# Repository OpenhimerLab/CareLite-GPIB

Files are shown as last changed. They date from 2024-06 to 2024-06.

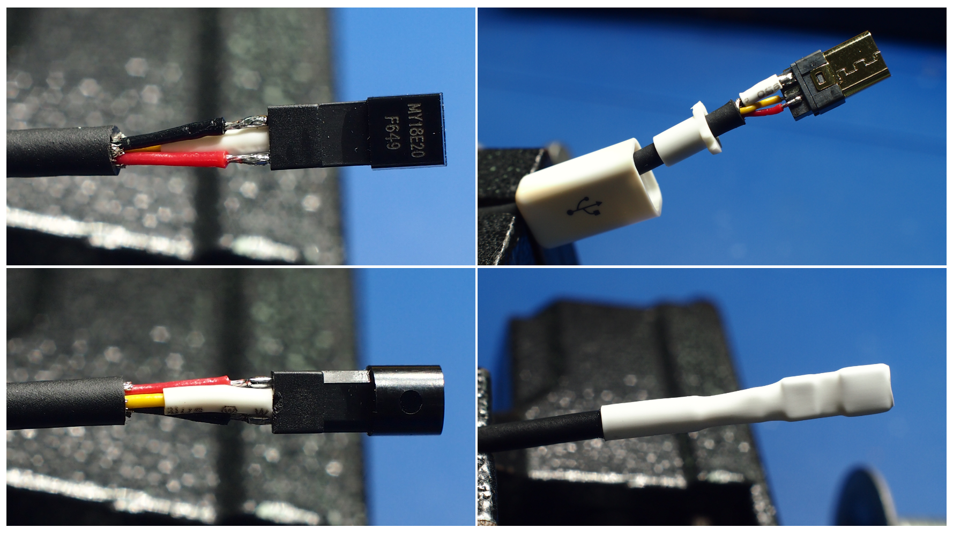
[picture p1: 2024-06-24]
HW/18B20 Soldering.png

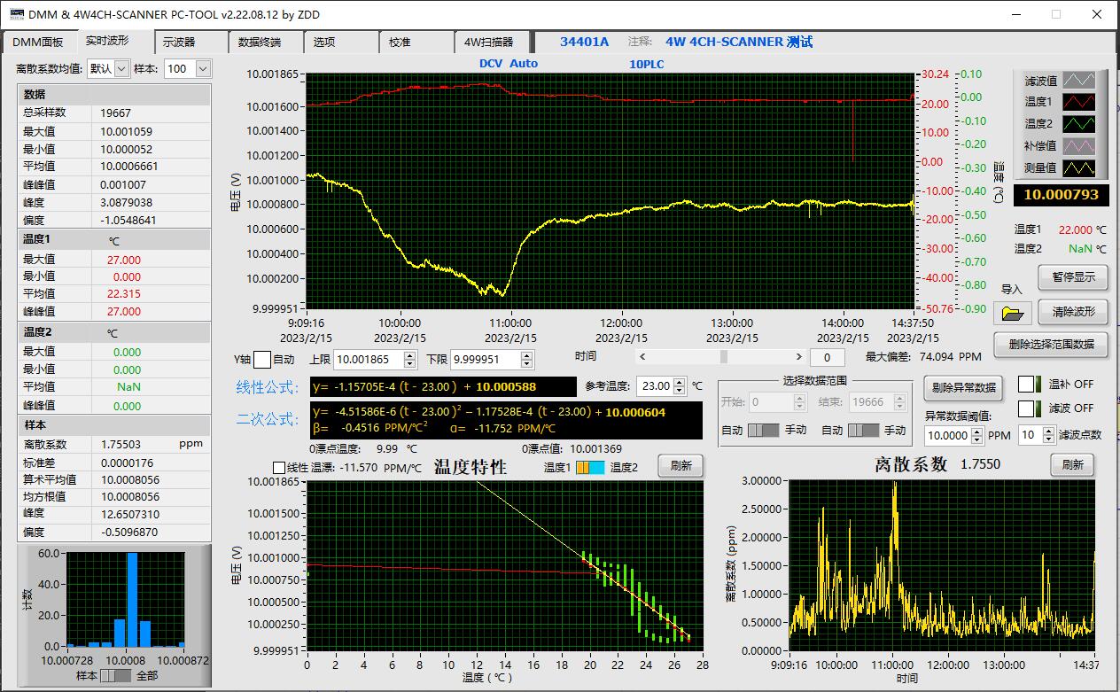
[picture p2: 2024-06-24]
PC Software 2.jpg

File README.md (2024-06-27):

# CareLite-GPIB
CareLite is an open-source, tiny, small USB-GPIB adaptor based on STM32 with temperature sensors. 
It uses VCP (Virtual COM Port) and USB Type-C connector, without the need for external power; 
also with dedicated PC software (but not limited to), 
easy GPIB connection can be established and Prologix-like command protocol makes the compatiblity better, and real-time temp logging can be done by DS18B20 or so.




****I am NOT the author with no any relationship or benefit conflict with the author. I have no commercial intention to introdue this project and I have no intention to make benefits from this. 
All responsibility and risk or financial loss should be taken by the DIYers yourselves. The project is introduced and shared "AS IS".
Many functions, issues may exisit so use it at your own risk.


There are 2 version of MeterCare USB-GPIB converter, while sharing the same PC host Software, the firmware is unclear that both version could be applied.
We choose to introduce and share the "Lite" version firstly, as it is a simple, costless design somehow like AR488, 
but the designer reserves potentials to expand other functionality like temperature, humidity sensing ability (there is an UART+DS18B20 port, with proper firmware, it can be amazing for its various functionality!).
Schematic_CareLite_V1 21

By the STM32F401, the CareLite can perform GPIB-USB conversion. 
In addition, there is a connector called MeterLink that provides the integration of multiple sensors(1 DS18B20 is confirmed to be functional).

PCB4

PCB3
PCB2

Till now, at least 1 DS18B20 OneWire Temperature sensor can be used for logging temperature (by using MeterLink).



PC Software 2

With the software written by "ZDD", you can connect a DMM and do a logging of both volt/ohm and temperature, and it will simutaneously calculate the math like temp.Co, or the deviation of logged data.
This makes it very clear to understand the dependency of multiple variables and its statistical property.


Also note that the software by ZDD is Labeview-based, you need to install:
1. NI Labview runtime
2. Local emulator to deal with encoding problems, as it is originally based on GBK simplified chinese, not UTF-8.
MultiTemp

A sensor board with BMP180 and DS18B20, SHT2X is also possible for environment data logging, there is UART1 definition in MeterLink;
so it might be possible functional. This expansion board is mainly for the "Care" USB-GPIB, not sure if it is functional on CareLite.
PC Software 1
SW in USE 2
SW in USE 1

The firmware is a bit messy, so try and find the best one for yourself. And explore the function, the Care ecosystem is very potential.
The protocol and communication is very like Prologix, using "++" command system, there are some explaination files, but it's in simplified Chinese,
for now I have no time to translate it, so please try by your own self. 
All in all, this is a tiny, easy to use GPIB adaptor for many devices, somthing like a STM32-based AR488 but with dedicated PC sotware!

For COPYright:


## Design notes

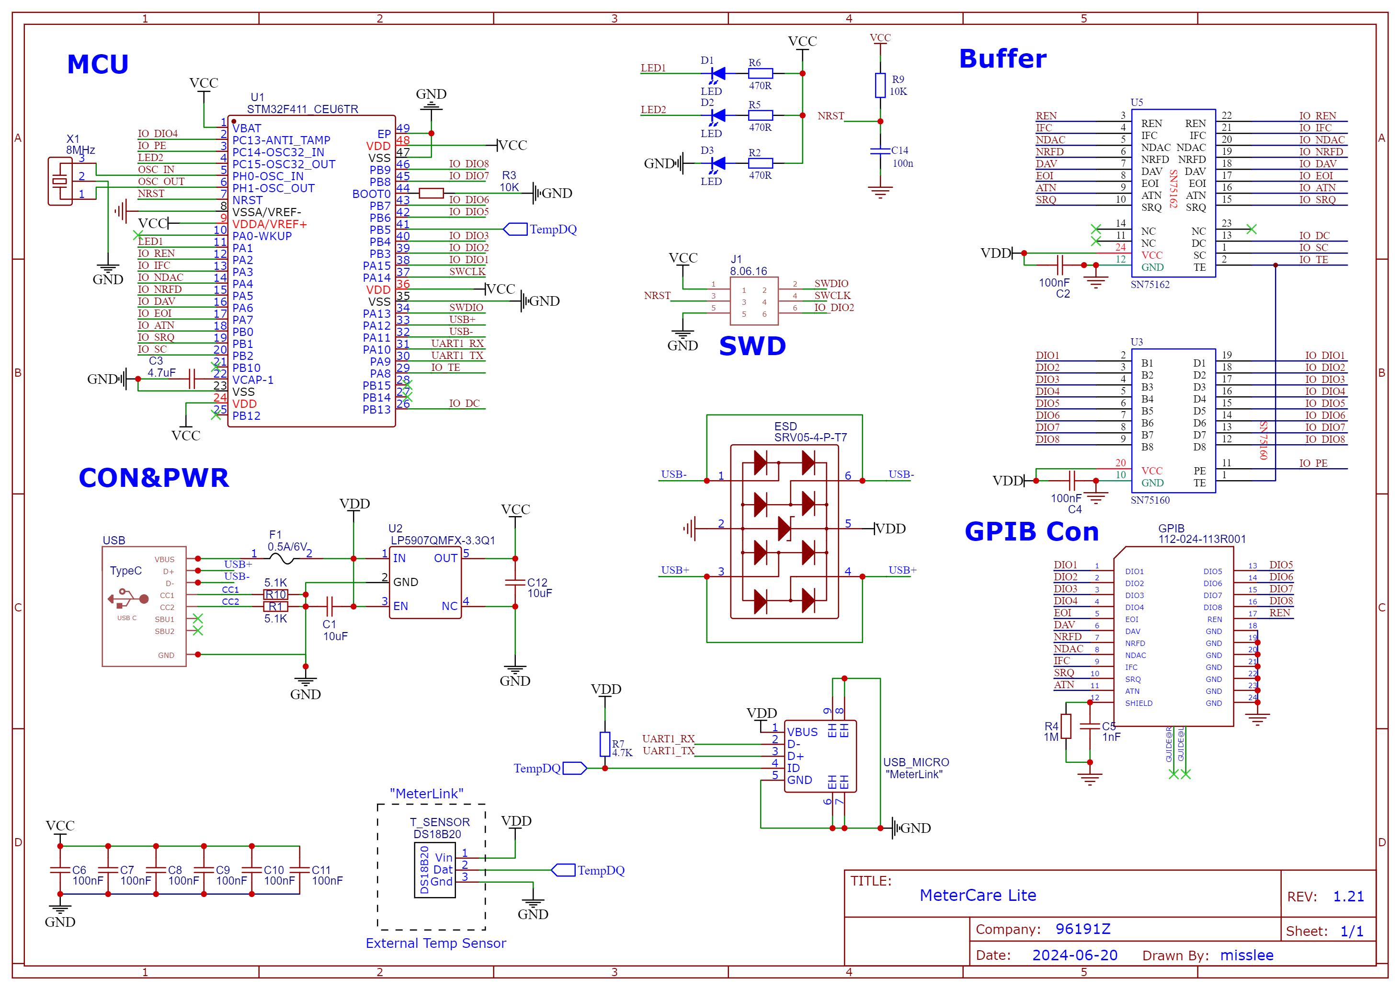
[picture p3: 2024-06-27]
Schematic_CareLite_V1.21.png

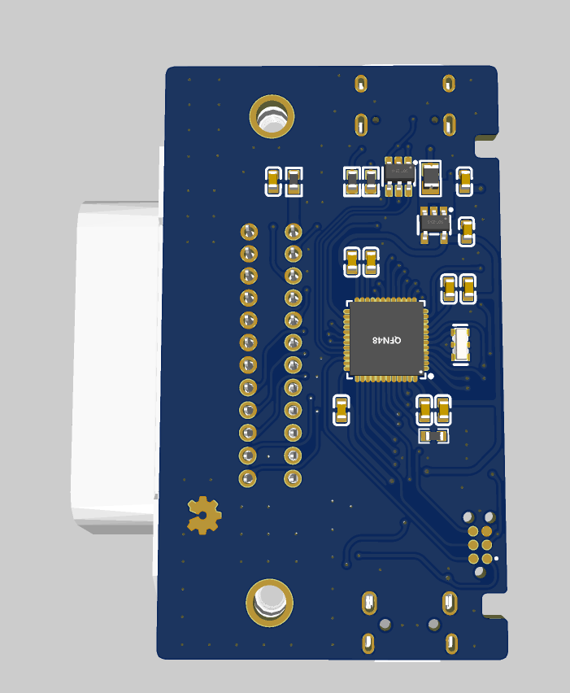
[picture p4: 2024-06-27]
PCB2.png

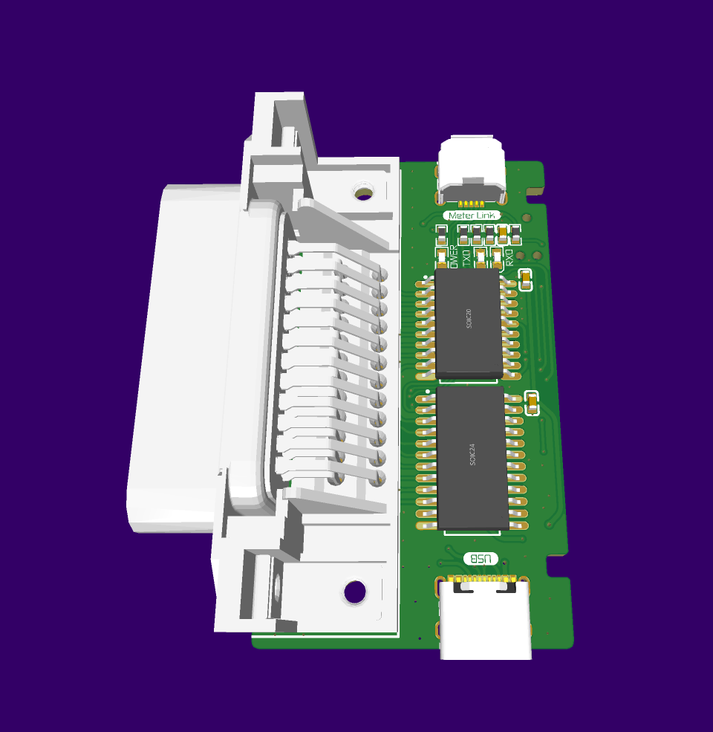
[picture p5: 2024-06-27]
PCB3.png

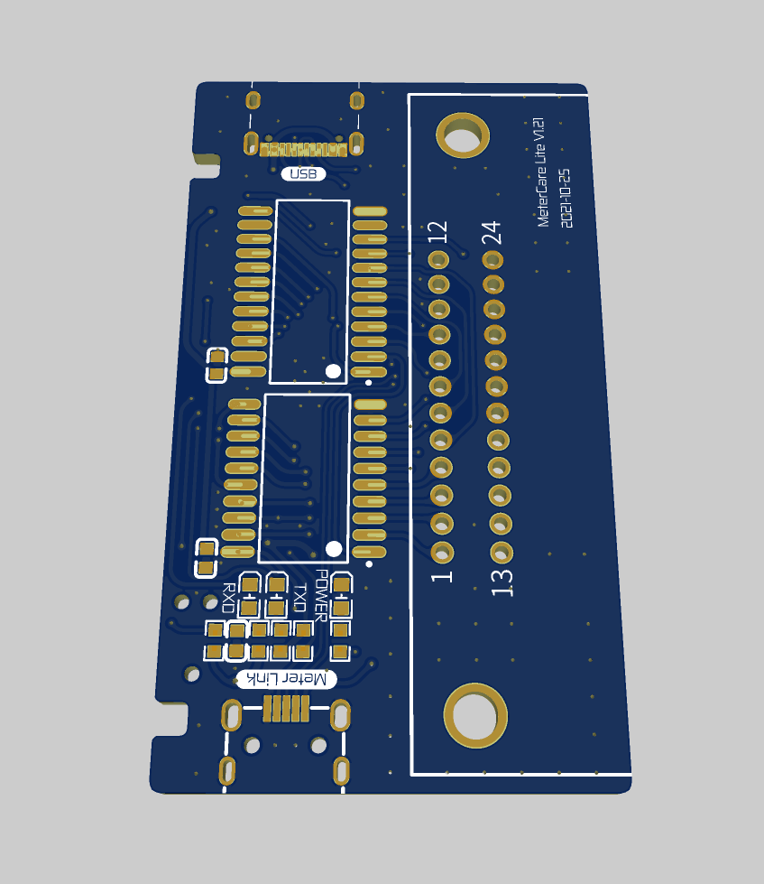
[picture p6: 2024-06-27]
PCB.png

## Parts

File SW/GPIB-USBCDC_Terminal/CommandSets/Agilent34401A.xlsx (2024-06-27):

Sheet: 仪器命令
命令内容 | 空格 | 分割符 | 空格 | 命令是否有返回信息(是:1,否0) | 空格 | 分割符 | 空格 | 命令说明信息
*IDN? |  | # |  | 1 |  | # |  | 询问仪器名称、版本等信息
*RST |  | # |  | 0 |  | # |  | 重置设置为默认值
*TST? |  | # |  | 0 |  | # |  | 仪器自检
SYSTem:ERRor? |  | # |  | 1 |  | # |  | 询问当前错误信息
*CLS |  | # |  | 0 |  | # |  | 清除错误
*CLS;:READ? |  | # |  | 1 |  | # |  | 读取当前值
*CLS;:MEASure:VOLTage:DC? 1E-1,1E-7 |  | # |  | 1 |  | # |  | 指定在100mv(0.1,1E-1 V),分辨率为(0.0000001,1E-7 ) (6位半)测量直流电压\n 该方式不具有灵活性,建议使用CONF:VOLT:DC 1E-1, 1E-7 ; :TRIG:SOUR BUS| IMMediate | EXTernal ; : READ? \n 或 CONF:VOLT:DC 1E-1, 1E-7 ; :TRIG:SOUR BUS | IMMediate | EXTernal ; : INIT ; :FETC? \n 这两种方式
*CLS;:CONFigure:VOLTage:DC 1E-1, 1E-7 ; :TRIG:SOURce IMMediate ;:READ? |  | # |  | 1 |  | # |  | 指定在100mV量程,6位半测量直流电压,\n触发方式为立即执行
*CLS;:CONFigure:VOLTage:DC 1E-2, 1E-7 ; :TRIG:SOURce IMMediate ; :INIT ; :FETC? |  | # |  | 1 |  | # |  | 指定在10mV量程,6位半测量交流电压(AC模式设置分辨率仅仅改变前面板显示,数据始终以6位半模式储存),\n触发方式为立即执行
*CLS;:CONFigure:CURRent:AC 1E-3, 1E-6 ; :TRIG:SOURce IMMediate ; :INIT ; :FETC? |  | # |  | 1 |  | # |  | 指定在1mA量程,5位半测量交流电流(AC电流最多支持5未半),\n触发方式为立即执行
*CLS;:CONFigure:RESistance ; :TRIG:SOURce IMMediate ; :INIT ; :FETC? |  | # |  | 1 |  | # |  | 双线测量电阻,测量电阻不要指定量程和分辨率
*CLS;:CONFigure:FRESistance ; :TRIG:SOURce IMMediate ; :INIT ; :FETC? |  | # |  | 1 |  | # |  | 四线测量电阻,测量电阻不要指定量程和分辨率
*CLS;:SENSe:DETector:BANDwidth? |  | # |  | 1 |  | # |  | 询问当前 AC 滤波器频率
*CLS;:SENSe:DETector:BANDwidth 20 |  | # |  | 0 |  | # |  | 设置当前 AC 滤波器频率 只有 3 ,20 ,200 可选，值越低，速度越慢
*CLS;:CONFigure:CONTinuity ; :TRIG:SOURce IMMediate ; :INIT ; :FETC? |  | # |  | 1 |  | # |  | 开路测试
*CLS;:CONFigure:DIODe ; :TRIG:SOURce IMMediate ; :INIT ; :FETC? |  | # |  | 1 |  | # |  | 二极管测试
*CLS;:SENSe:FUNCtion "VOLTage:DC" |  | # |  | 0 |  | # |  | 使用直流电压测量功能
*CLS;:SENSe:FUNCtion "CURRent:AC" |  | # |  | 0 |  | # |  | 使用交流电流测量功能
*CLS;:SENSe:FUNCtion? |  | # |  | 1 |  | # |  | 当前使用的功能
*CLS;:SENSe:FUNCtion "PERiod" |  | # |  | 0 |  | # |  | 周期测量功能
*CLS;:SENSe:FUNCtion "FREQuency" |  | # |  | 0 |  | # |  | 频率测量功能
*CLS;:SENSe:FUNCtion "VOLTage:DC:RATio" |  | # |  | 0 |  | # |  | DC信号电压与参考电压比率
*CLS;:DISPlay OFF |  | # |  | 0 |  | # |  | 关闭仪器面板显示
*CLS;:DISPlay ON |  | # |  | 0 |  | # |  | 开启仪器面板显示
*CLS;:DISPlay? |  | # |  | 1 |  | # |  | 询问当前仪器屏幕是否开启
*CLS;:DISPlay:TEXT "HelloAgilent" |  | # |  | 0 |  | # |  | 将字符串 "HelloAgilent" 显示到仪器屏幕显示
*CLS;:DISPlay:TEXT:CLEar |  | # |  | 0 |  | # |  | 清除屏幕显示的文字
*CLS;:DISPlay:TEXT? |  | # |  | 1 |  | # |  | 询问当前仪器屏幕上显示的内容
*CLS;:SYSTem:BEEPer |  | # |  | 0 |  | # |  | 让仪器发出一声蜂鸣
*CLS;:SYSTem:BEEPer:STATe ON |  | # |  | 0 |  | # |  | 开启仪器蜂鸣
*CLS;:SYSTem:BEEPer:STATe? |  | # |  | 1 |  | # |  | 询问当前蜂鸣器状态
 |  | # |  |  |  | #
 |  | # |  |  |  | #
 |  | # |  |  |  | #
 |  | # |  |  |  | #
 |  | # |  |  |  | #
 |  |  |  |  |  | #

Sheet: 正则表达式
#RegexExpression标识（!2） | 空格 | 表达式内容 | 空格 | 分割符 | 空格 | 表达式说明信息
!2 |  | ([A-Za-z]{7}-)|([0-9]{5})|([0-9]) |  | # |  | 取出7个字母加一个减号(-)的部分 \n接着往后 取出一个5位数 最后取出 一位数
!2
!2
!2
!2
!2
!2
!2
!2
!2
!2
!2
!2
!2
!2
!2
!2
!2
!2
!2

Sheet: GNUCoreutils命令
#GNUCoreutils命令 标识 ！3 | 空格 | 表达式内容 | 空格 | 分割符 | 空格 | 表达式说明信息
!3 |  | awk -F, "{print $1 \" \" $2}" |  | # |  | 取出以逗号","为分割符的第一列 第二列，第一列和第二列之间用空格分隔
!3 |  | tr "[A-Z]" "[a-z}" |  | # |  | 转换所有大写字母为小写
!3 |  | tr [:lower:] [:upper:] |  | # |  | 转换所有小写字母为大写
!3 |  | tr [:upper:] [:lower:] | sed -e "s/\b\(.\)/\u\1/g" |  | # |  | 只大写单词的第一个字母,其它所有字母小写
!3 |  | tr [:upper:] [:lower:] | sed -e "s/\b\(.\)/\u\1/g" | sed "s@[^a-zA-Z][a-z][^a-zA-Z]@\U&@g" |  | # |  | 只大写单词的第一个字母,但是单个字母的全部大写
!3 |  |  |  | #
!3 |  |  |  | #
!3 |  |  |  | #
!3 |  |  |  | #
!3 |  |  |  | #
!3 |  |  |  | #
!3 |  |  |  | #
!3 |  |  |  | #
!3 |  |  |  | #
!3 |  |  |  | #
!3 |  |  |  | #
!3 |  |  |  | #
!3 |  |  |  | #
!3 |  |  |  | #
!3 |  |  |  | #
!3 |  |  |  | #
!3 |  |  |  | #
!3 |  |  |  | #
 |  |  |  | #

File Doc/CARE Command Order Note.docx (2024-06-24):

字符串命令

一．基本设置

USB连接之后串口设置，115200，N，8，1

字符串命令时候串口以及TCP调试都需要“\r\n”(0x0D 0x0A)作为结束，返回命令也都是“\r\n”(0x0D 0x0A)作为结束

开机默认透传GPIB地址为23，自动收发模式，不改变任何设置直接和23地址字符串透传，自动收发模式。如下图，23地址为3458，直接发送3458的采集命令“DCV 10”，自动返回测量数据

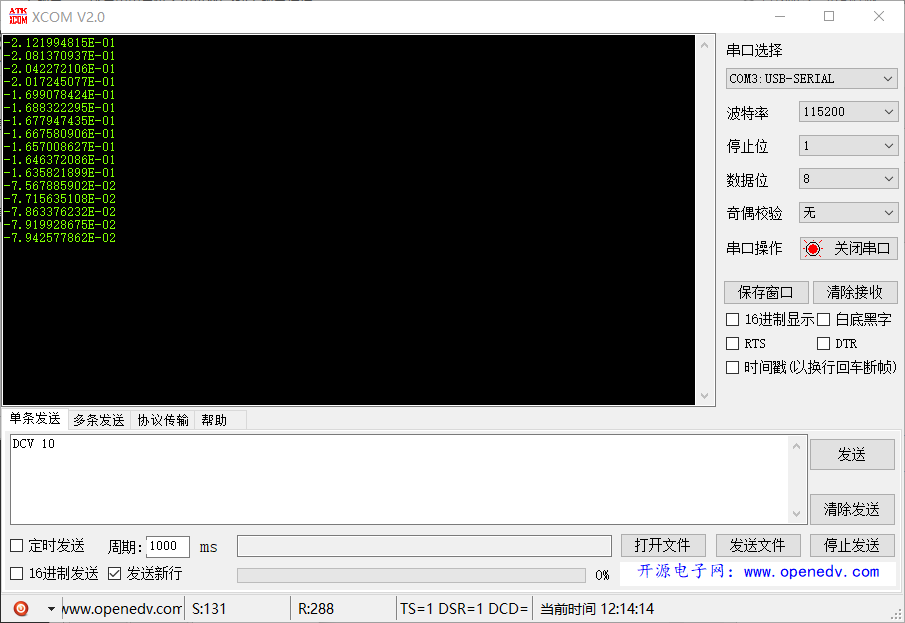
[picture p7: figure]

二．测试命令：CARE?

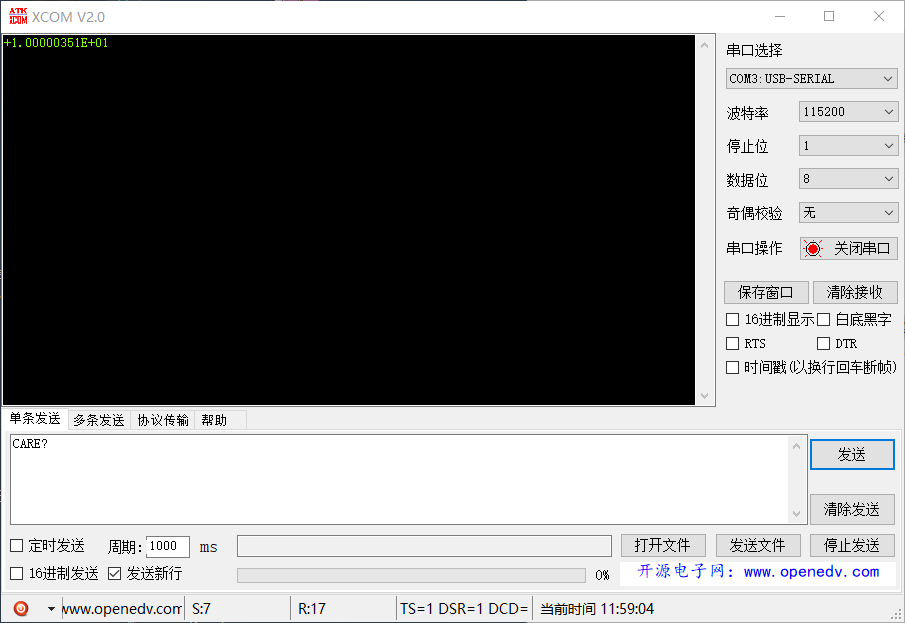
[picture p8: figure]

三．LAN连接IP获得：CARE_IP? （LAN IP地址，获取WIFI地址命令暂时还在测试）

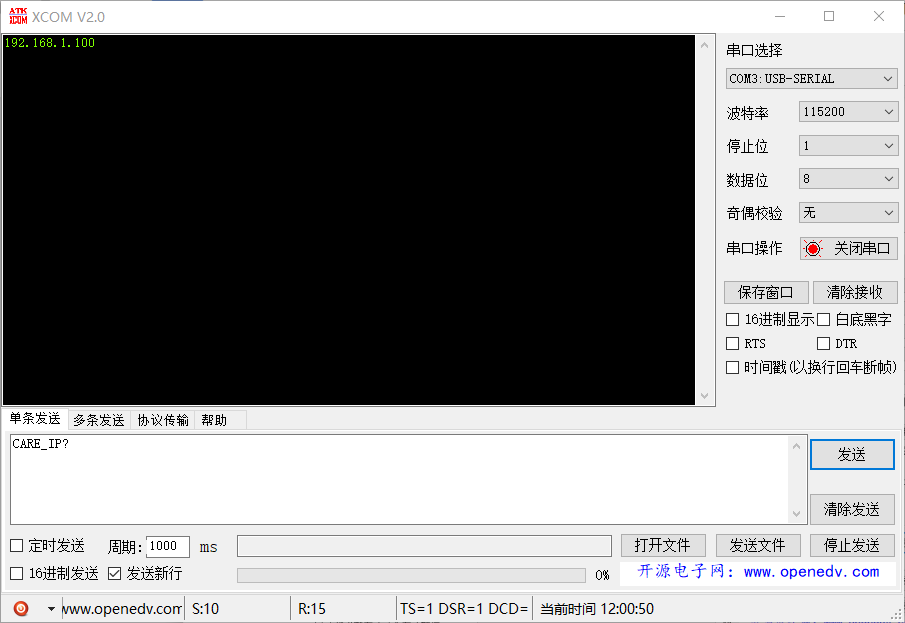
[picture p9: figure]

四．WIFI_GPIB重启：CARE_RESET

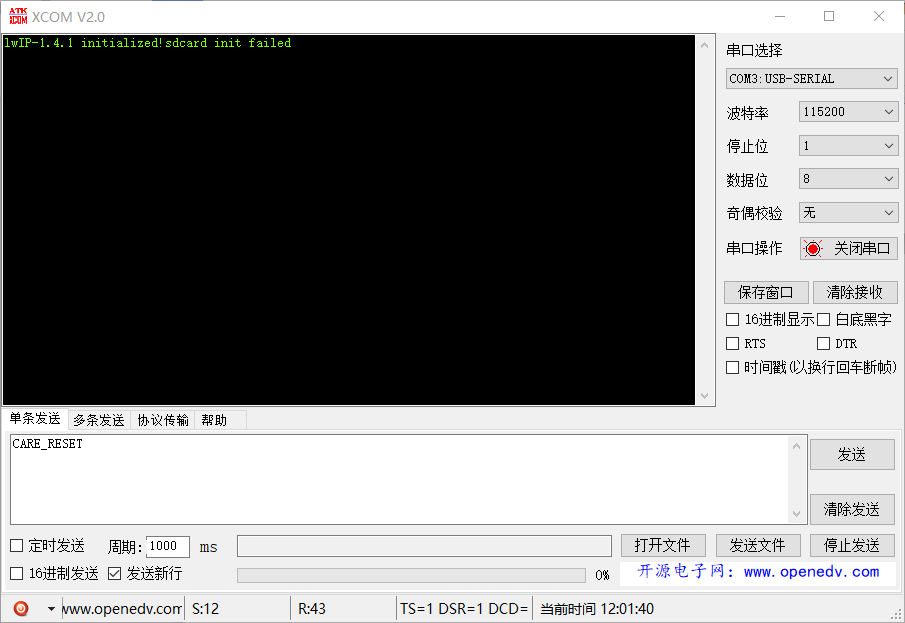
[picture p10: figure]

五．电池电压：CARE_VOLT? （0413位4.13V）

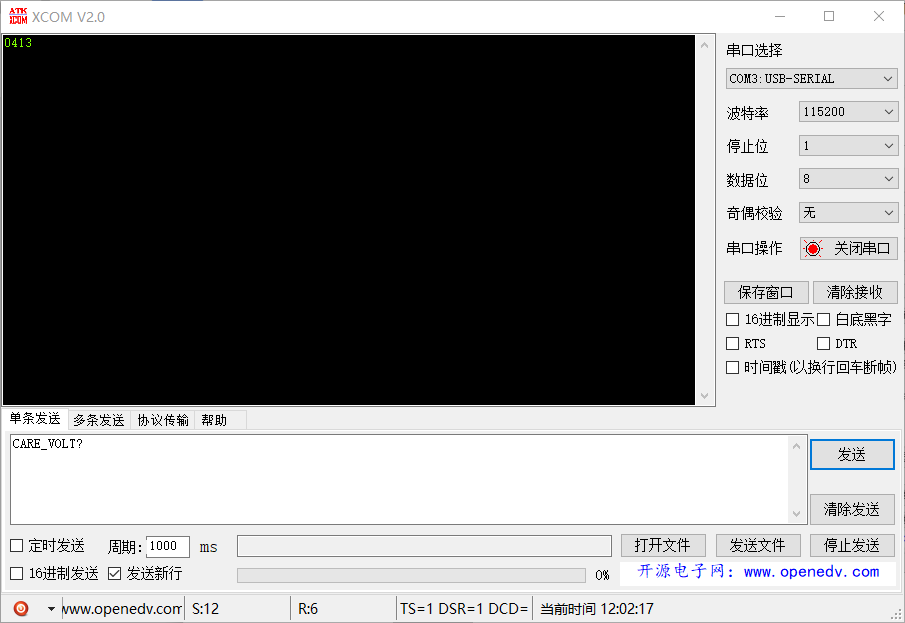
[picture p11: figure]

6． 改变透传地址：CARE_ADDR:22 （22为设置的新地址）

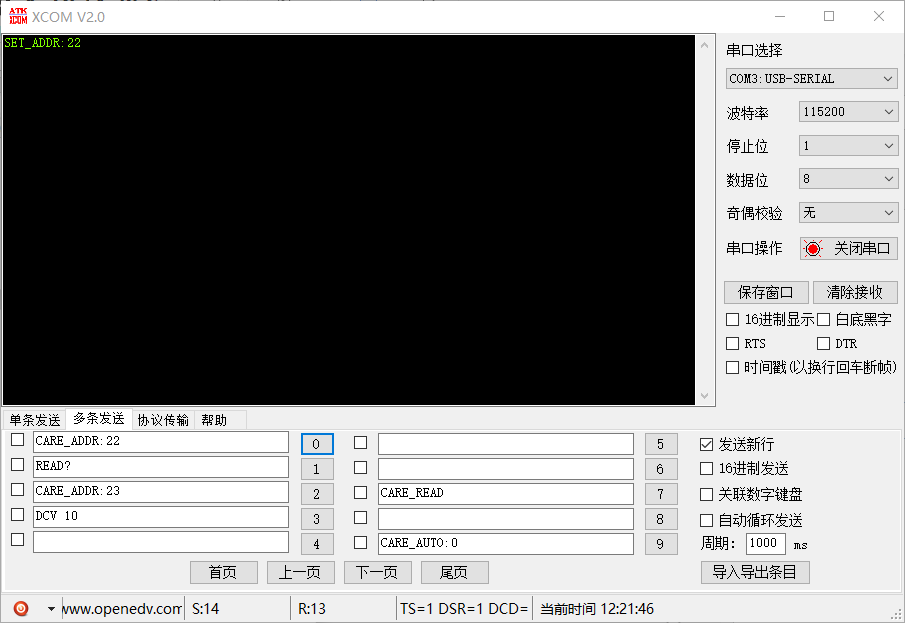
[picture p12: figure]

7． 改变自动收发模式：CARE_AUTO:1 （1|0为打开或关闭自动收发模式）

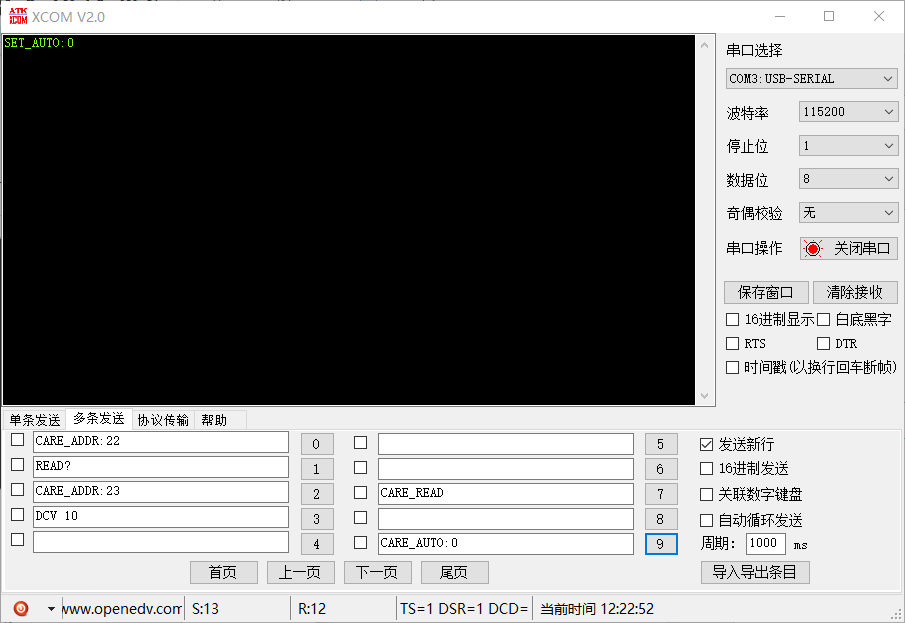
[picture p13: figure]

8． 关闭自动收发模式时候读取数据：CARE_READ

依次发送命令(22地址为AG34401)

1. CARE_AUTO:0 （关闭自动收发模式）
2. CARE_ADDR:22 （改变当前仪表地址）
3. READ? （发送AG34401采集命令READ?）
4. CARE_READ （发送命令由WIFI-GPIB回读34401数据）

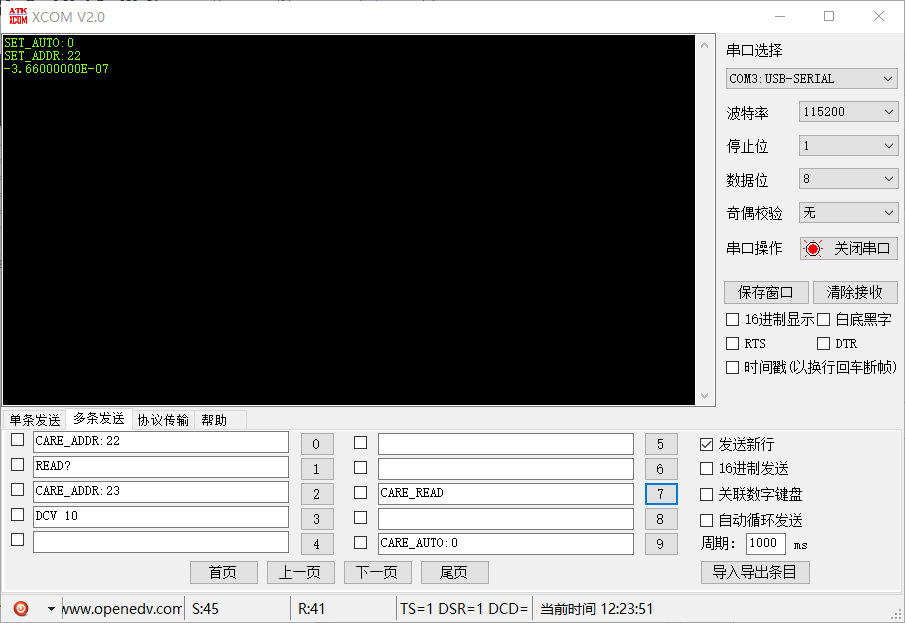
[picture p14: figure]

九．多个仪表连接实例：（22为AG34401，23为3458）

1. CARE_AUTO:0 （关闭自动收发模式）
2. CARE_ADDR:22 （改变当前仪表地址为22）
3. READ? （发送AG34401采集命令READ?）
4. CARE_ADDR:23 （改变当前仪表地址为23）
5. DCV 10 （发送HP3458采集命令DCV 10）
6. CARE_ADDR:22 （改变当前仪表地址为22）
7. CARE_READ （发送命令由WIFI-GPIB回读34401数据）
8. 得到34401采集数据
9. CARE_ADDR:23 （改变当前仪表地址为23）
10. CARE_READ （发送命令由WIFI-GPIB回读34401数据）
11. 得到3458采集数据

十．释放仪表到LOCAL状态：CARE_LOC

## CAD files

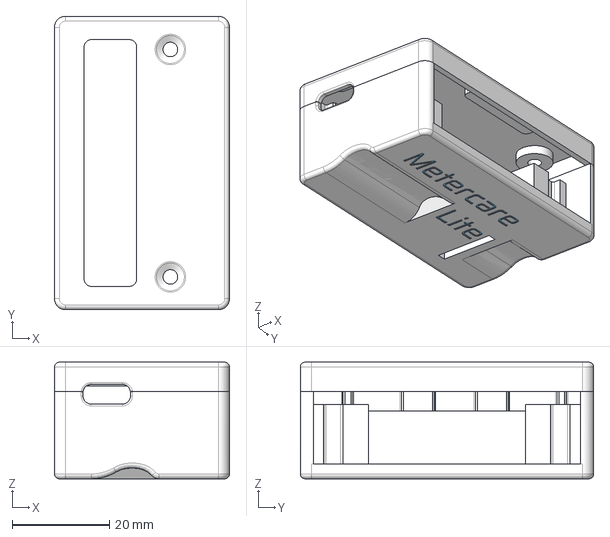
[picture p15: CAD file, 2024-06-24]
Case 3D/metercare lite Ver0.23.step
36.0 x 60.4 x 24.0 mm

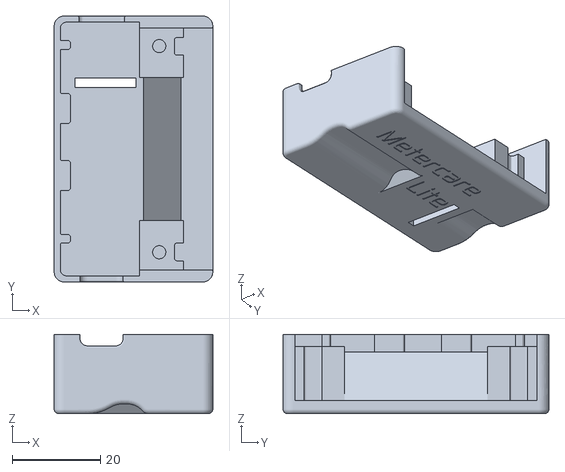
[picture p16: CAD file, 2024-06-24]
Case 3D/Top.STL
36.0 x 60.4 x 18.0

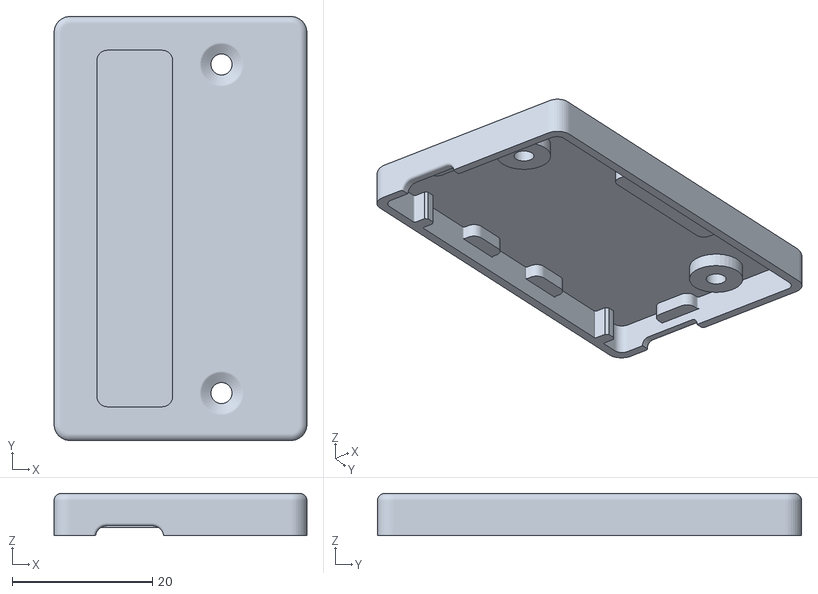
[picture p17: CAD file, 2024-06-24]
Case 3D/Bottom.STL
36.0 x 60.4 x 6.00

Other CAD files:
Case 3D/metercare lite Ver0.23.STL

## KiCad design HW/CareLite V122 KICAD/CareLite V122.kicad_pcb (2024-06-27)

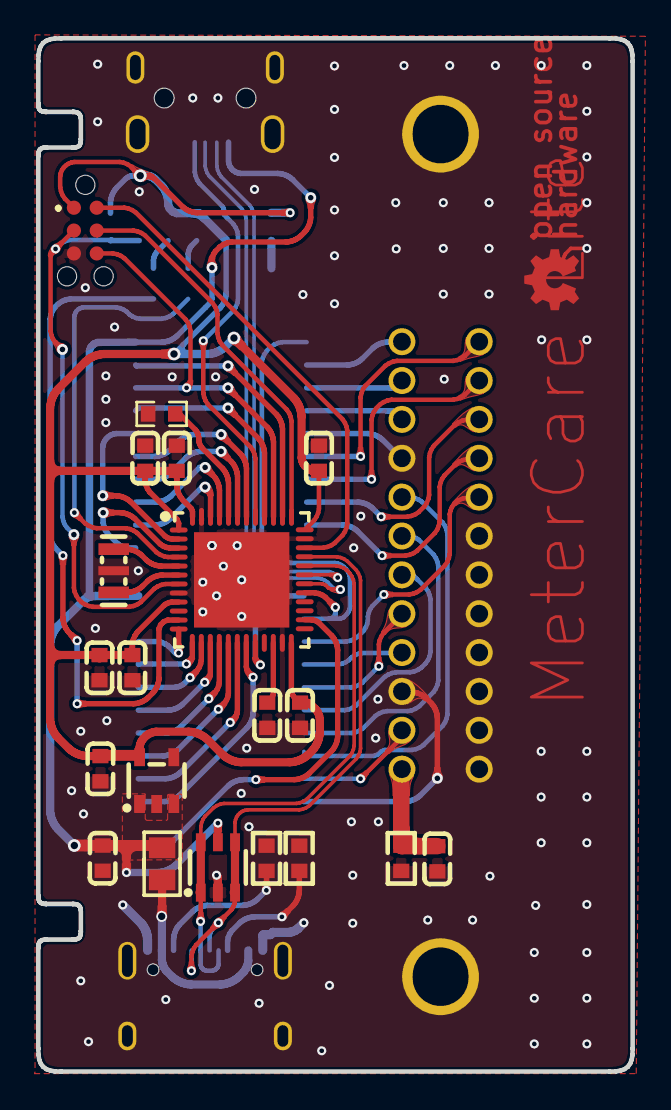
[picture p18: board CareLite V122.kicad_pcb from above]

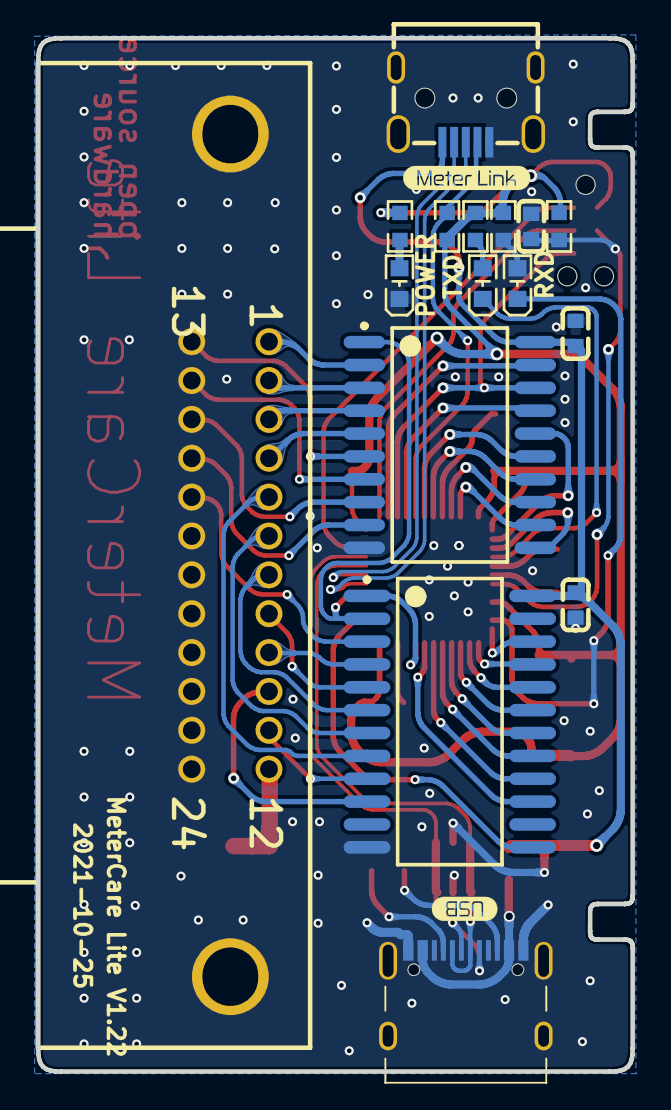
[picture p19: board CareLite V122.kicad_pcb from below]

Board: 2 copper layers, 33.0 x 57.4 mm, 37 parts (16 on the bottom side), 60 nets.

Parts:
C1, C12: 10uF; C0603
C2, C4, C6, C7, C8, C9, C10, C11: 100nF; C0603
C3: 4.7uF; C0603
C5: 1nF; C0603
C14: 100n; C0603
D1, D2, D3: LED; LED0603-FD
ESD: SRV05-4-P-T7; SOT-23-6_L2.9-W1.6-P0.95-LS2.8-BL
F1: 0.5A/6V; 0805_L_JX
GPIB: 112-024-113R001; IEEE-488 SOCKET, 24PIN, RIGHT ANGLE, MALE, 112-024-113R001,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
J1: 8.06.16; 80616-S
Pad_gge8544: Pad_gge8544
R1, R10: 5.1K; R0603
R2, R5, R6: 470R; R0603
R3, R9: 10K; R0603
R4: 1M; R0603
R7: 4.7K; R0603
U1: STM32F411CEU6TR; QFN-48_L7.0-W7.0-P0.50-BL-EP5.1
U2: LP5907QMFX-3.3Q1; SOT-23-5_L3.0-W1.7-P0.95-LS2.8-BR
U3: SN75160; SOIC127P1030-20AM
U5: SN75162; SOIC127P1030-24AM
USB: USB_C; USB_C_CUSB31-CFM2AX-01-Y
USB1: U-D-M7DS-G-2; MIRCO-USB-SMD_U-D-M7DS-G-2
X1: 8MHz; OSC-SMD_3P-L3.2-W1.3-P1.2-L

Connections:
ATN: GPIB.11, U5.9
CC1: R10.1, USB.A5
CC2: R1.1, USB.B5
D2_1: D2.1, R5.2
DAV: GPIB.6, U5.7
DIO1: GPIB.1, U3.2
DIO2: GPIB.2, U3.3
DIO3: GPIB.3, U3.4
DIO4: GPIB.4, U3.5
DIO5: GPIB.13, U3.6
DIO6: GPIB.14, U3.7
DIO7: GPIB.15, U3.8
DIO8: GPIB.16, U3.9
DS18B20: R7.2, U1.41, USB1.4
EOI: GPIB.5, U5.8
F1_1: F1.1, USB.A4B9, USB.B4A9
GND: C1.1, C2.2, C3.1, C4.2, C5.1, C6.1, C7.1, C8.1, C9.1, C10.1, C11.1, C12.1, C14.1, D3.2, ESD.2, GPIB.18, GPIB.19, GPIB.20, GPIB.21, GPIB.22, GPIB.23, GPIB.24, J1.5, R1.2, R3.2, R4.2, R10.2, U1.8, U1.23, U1.35, U1.47, U1.49, U2.2, U2.4, U3.10, U5.12, USB.A1B12, USB.B1A12, USB1.5, USB1.6, USB1.7, USB1.8, USB1.9, X1.2
GPIB_12: C5.2, GPIB.12, R4.1
IFC: GPIB.9, U5.4
IO_ATN: U1.18, U5.16
IO_DAV: U1.16, U5.18
IO_DC: U1.26, U5.13
IO_DIO1: U1.38, U3.19
IO_DIO2: J1.6, U1.39, U3.18
IO_DIO3: U1.40, U3.17
IO_DIO4: U1.2, U3.16
IO_DIO5: U1.42, U3.15
IO_DIO6: U1.43, U3.14
IO_DIO7: U1.45, U3.13
IO_DIO8: U1.46, U3.12
IO_EOI: U1.17, U5.17
IO_IFC: U1.13, U5.21
IO_NDAC: U1.14, U5.20
IO_NRFD: U1.15, U5.19
IO_PE: U1.3, U3.11
IO_REN: U1.12, U5.22
IO_SC: U1.20, U5.1
IO_SRQ: U1.19, U5.15
IO_TE: U1.29, U3.1, U5.2
LED1: D1.2, U1.11
LED2: D2.2, U1.4
NDAC: GPIB.8, U5.5
NRFD: GPIB.7, U5.6
NRST: C14.2, J1.3, R9.1, U1.7
OSC_IN: U1.5, X1.3
OSC_OUT: U1.6, X1.1
R2_2: D3.1, R2.2
R6_2: D1.1, R6.2
REN: GPIB.17, U5.3
SRQ: GPIB.10, U5.10
SWCLK: J1.4, U1.37
SWDIO: J1.2, U1.34
U1_22: C3.2, U1.22
U1_44: R3.1, U1.44
UART1_RX: U1.31, USB1.2
UART1_TX: U1.30, USB1.3
USB+: ESD.3, ESD.4, U1.33, USB.A6, USB.B6
USB-: ESD.1, ESD.6, U1.32, USB.A7, USB.B7
VCC: C6.2, C7.2, C8.2, C9.2, C10.2, C11.2, C12.2, J1.1, R2.1, R5.1, R6.1, R7.1, R9.2, U1.1, U1.9, U1.24, U1.36, U1.48, U2.5
VDD: C1.2, C2.1, C4.1, ESD.5, F1.2, U2.1, U2.3, U3.20, U5.24, USB1.1

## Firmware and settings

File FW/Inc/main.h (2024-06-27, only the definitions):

#define DIO4_Pin LL_GPIO_PIN_13
#define DIO4_GPIO_Port GPIOC
#define PE_Pin LL_GPIO_PIN_14
#define PE_GPIO_Port GPIOC
#define LED2_Pin LL_GPIO_PIN_15
#define LED2_GPIO_Port GPIOC
#define LED1_Pin LL_GPIO_PIN_1
#define LED1_GPIO_Port GPIOA
#define REN_Pin LL_GPIO_PIN_2
#define REN_GPIO_Port GPIOA
#define IFC_Pin LL_GPIO_PIN_3
#define IFC_GPIO_Port GPIOA
#define NDAC_Pin LL_GPIO_PIN_4
#define NDAC_GPIO_Port GPIOA
#define NRFD_Pin LL_GPIO_PIN_5
#define NRFD_GPIO_Port GPIOA
#define DAV_Pin LL_GPIO_PIN_6
#define DAV_GPIO_Port GPIOA
#define EOI_Pin LL_GPIO_PIN_7
#define EOI_GPIO_Port GPIOA
#define ATN_Pin LL_GPIO_PIN_0
#define ATN_GPIO_Port GPIOB
#define SRQ_Pin LL_GPIO_PIN_1
#define SRQ_GPIO_Port GPIOB
#define SC_Pin LL_GPIO_PIN_2
#define SC_GPIO_Port GPIOB
#define DC_Pin LL_GPIO_PIN_13
#define DC_GPIO_Port GPIOB
#define TE_Pin LL_GPIO_PIN_8
#define TE_GPIO_Port GPIOA
#define DIO1_Pin LL_GPIO_PIN_15
#define DIO1_GPIO_Port GPIOA
#define DIO2_Pin LL_GPIO_PIN_3
#define DIO2_GPIO_Port GPIOB
#define DIO3_Pin LL_GPIO_PIN_4
#define DIO3_GPIO_Port GPIOB
#define DS18B20_Pin LL_GPIO_PIN_5
#define DS18B20_GPIO_Port GPIOB
#define DIO5_Pin LL_GPIO_PIN_6
#define DIO5_GPIO_Port GPIOB
#define DIO6_Pin LL_GPIO_PIN_7
#define DIO6_GPIO_Port GPIOB
#define DIO7_Pin LL_GPIO_PIN_8
#define DIO7_GPIO_Port GPIOB
#define DIO8_Pin LL_GPIO_PIN_9
#define DIO8_GPIO_Port GPIOB

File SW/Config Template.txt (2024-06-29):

[Agilent 34401A English Template 2024]

;This template could modified for adding new models into PC-TOOL. Rename this config file as device’s type, eg. HP34460A, then “HP34460A” will be recognized by the system. 

;This template is a universal config with nearly every function that DMM might have; so it is obvious that you have to disable something that the new DMM model does not support or create something specifically that it supports.

;The symbol “;” will not be read as a command but might be use in command text as a combination expression, if that case, it is a command. 
; The symbol “,” is used in command or parameter separator.
;DO NOT modify anything on the left of “=” symbol. 

; The command on the left of “=” are 
Button name/ Command, Command availability, Get range, Get Auto-Range, Get Auto-Zero, Get NPLC, Get digits, Get Input Z, Set Null, Range(from low to high)。

;0: DCV，1; ACV, 2: 2WR, 3: 4WR, 4: DCA, 5:ACA, 6: Freq, 7: Period, 8: Continuity, 9: Diode, 10: Ratio, 11: Temp, 12: Capacitance

;Note: Fill in 0 if the function is not supported by DMM or Software (Continuity if currently not supported by software).

; Only Scientific notation and decimal are supported, not prefixes like u/m/K/M.

; If there is not corresponding command of the function, put in 「-」, and leave blank after that.







;==================Main Commands===========================
0=DCV,CONF:VOLT,1,VOLT:DC:RANG?,VOLT:DC:RANG:AUTO?,ZERO:AUTO?,VOLT:DC:NPLC?,-,INP:IMP:AUTO?,CALC:FUNC NULL;:CALC:STAT ON,0.1,1,10,100,1000
1=ACV,CONF:VOLT:AC,1,VOLT:AC:RANG?,VOLT:AC:RANG:AUTO?,-,-,-,-,CALC:FUNC NULL;:CALC:STAT ON,0.1,1,10,100,750
2=Ω 2W,CONF:RES,1,RES:RANG?,RES:RANG:AUTO?,ZERO:AUTO?,RES:NPLC?,-,-,CALC:FUNC NULL;:CALC:STAT ON,100,1E+3,1E+4,1E+5,1E+6,1E+7,1E+8
3=Ω 4W,CONF:FRES,1,FRES:RANG?,FRES:RANG:AUTO?,ZERO:AUTO?,FRES:NPLC?,-,-,CALC:FUNC NULL;:CALC:STAT ON,100,1E+3,1E+4,1E+5,1E+6,1E+7,1E+8
4=DCI,CONF:CURR,1,CURR:RANG?,CURR:RANG:AUTO?,ZERO:AUTO?,CURR:NPLC?,-,-,CALC:FUNC NULL;:CALC:STAT ON,1E-2,1E-1,1,3
5=ACI,CONF:CURR:AC,1,CURR:AC:RANG?,CURR:AC:RANG:AUTO?,-,-,-,-,CALC:FUNC NULL;:CALC:STAT ON,1,3
6=FREQ,CONF:FREQ,1,FREQ:VOLT:RANG?,FREQ:VOLT:RANG:AUTO?,-,-,-,-,CALC:FUNC NULL;:CALC:STAT ON,0.1,1,10,100,750
7=PERIOD,CONF:PER,1,PER:VOLT:RANG?,PER:VOLT:RANG:AUTO?,-,-,-,-,CALC:FUNC NULL;:CALC:STAT ON,0.1,1,10,100,750
8=DIODE,CONF:DIOD,1
9=DC:RAT,CONF:RAT,1,VOLT:DC:RANG?,VOLT:DC:RANG:AUTO?,-,VOLT:DC:NPLC?,-,INP:IMP:AUTO?,-,0.1,1,10,100,1000
10=TEMP,CONF:TEMP,0
11=CAP,CONF:CAP,0
;=================End============================










;******General Commands**********

; ===Read Measurement (Always ON)
Read=READ?

; ===Prefix and decimal format (Always ON)
Prefix=0,0,0,0,0,0,0,0,0,0,0,0

; ===NPLC Range
NPLC=0.02,0.2,1,10,100

;===Max Digit(for 8.5 digits fills in 8 while default is 6)
maxDIG=6

;===Max Digit if not specified
;setMaxDIG=7

;===If the following commands are not needed or necessary, put「;」 in front====

; ===Get command config
getCONF=CONF?

; ===Get DMM ID
;getID=ID?

; ===Get Error info (Default SYST:ERR?)
;getERR=ERRSTR?

; ===Set Trigger sample count (used in Oscilloscope mode, default=1)
Sample=SAMP:COUN

; ===Set Display Config
DispOn=DISP ON
DispOff=DISP OFF



; ===Get Display Command
getDisp=DISP?

; ===Display Readback
DispText=DISP:TEXT "

; ===Clear Display Readback Text
ClrText=DISP:TEXT:CLE

; ===Local or Remote Command (Only serial COM mode, disable with “;”)
Remote=SYST:REM
Local=SYST:LOC

; ===Initial Commands Off
;Init=INIT:CONT OFF

;=== Default Header off
;:SYST:HEAD OFF

;===Set Command after disconnected
;End=INIT:CONT ON

;===Auto-Self-Cal Command
;Acal=*CAL?

; ===Auto-Self-Cal Parameter (use “,” as sepetator)
;AcalPara=

; ===Set Temp Sensor Config (FRTD,RTD,FTH,THER,TC/Sensor type use ”,”/ Sensor selectable parameter use “space”)
;TempSensor=FRTD:85,RTD:85,FTH:2252 5000 10000,THER:2252 5000 10000

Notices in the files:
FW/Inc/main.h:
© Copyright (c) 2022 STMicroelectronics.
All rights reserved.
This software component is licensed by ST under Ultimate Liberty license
